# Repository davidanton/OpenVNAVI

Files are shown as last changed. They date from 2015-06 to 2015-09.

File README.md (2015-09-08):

# OpenVNAVI

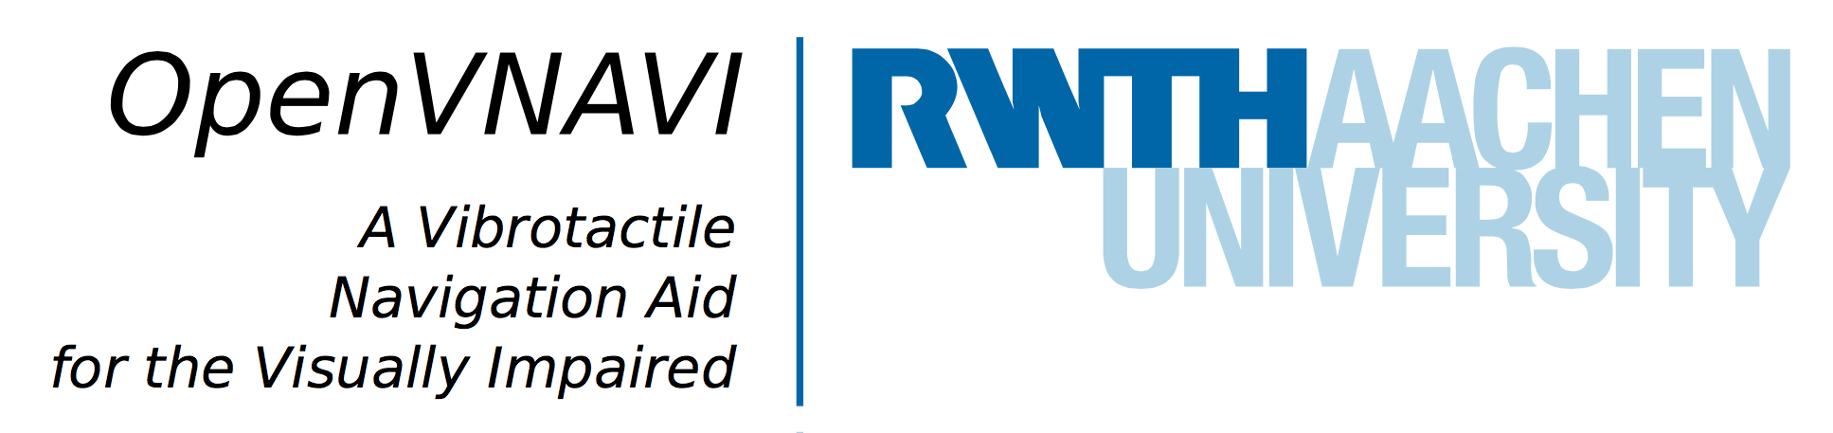
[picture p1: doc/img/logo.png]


**Bachelor Thesis at the Media Computing Group, Computer Science Department @ RWTH Aachen University (Germany)**
**Author:** [David Antón Sánchez](https://hci.rwth-aachen.de/sanchez)
**Project Website:** https://hci.rwth-aachen.de/openvnavi

---
#Wiki

- [Home](https://github.com/davidanton/OpenVNAVI/wiki)

- [Setting Up the Raspberry Pi 2](https://github.com/davidanton/OpenVNAVI/wiki/Setting-Up-the-Raspberry-Pi-2)

---

###System Description

OpenVNAVI is a vest equipped with a depth sensor and array of vibration motor units that allow people with visual impairment to avoid obstacles in the environment.

The ASUS Xtion PRO LIVE depth sensor, positioned onto the user’s chest scans the environment as the user moves. From the video feed of the depth sensor a frame is captured and then processed by the Raspberry Pi 2. Each frame is downsampled from 640x480 to 16x8 and each pixel is then mapped to a vibration motor unit forming an array positioned onto the user’s belly.

The grayscale value of each pixel on the lower resolution frame is assigned to a PWM voltage value generated by the Raspberry Pi 2 via PWM drivers that will drive each vibration motor obtaining a vibration amplitude value as a function of the proximity of an object.

With this method the vibration motor unit array is able to represent a vibratory image onto the user’s belly to help create a mental representation of the obstacles in the scene.

---

###Pictures

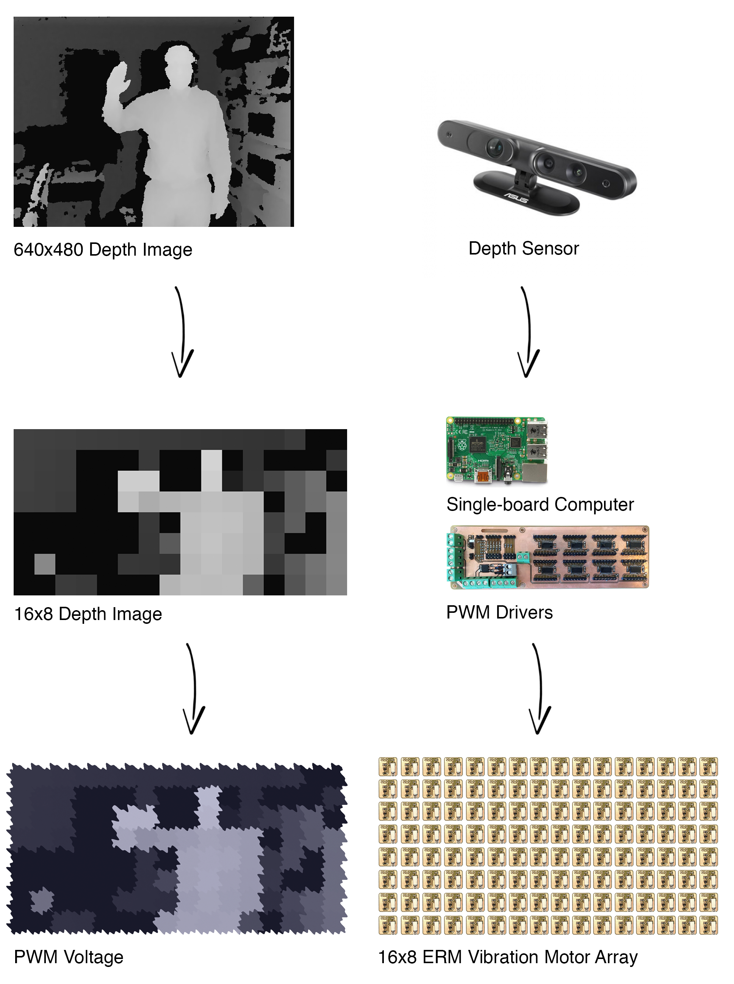
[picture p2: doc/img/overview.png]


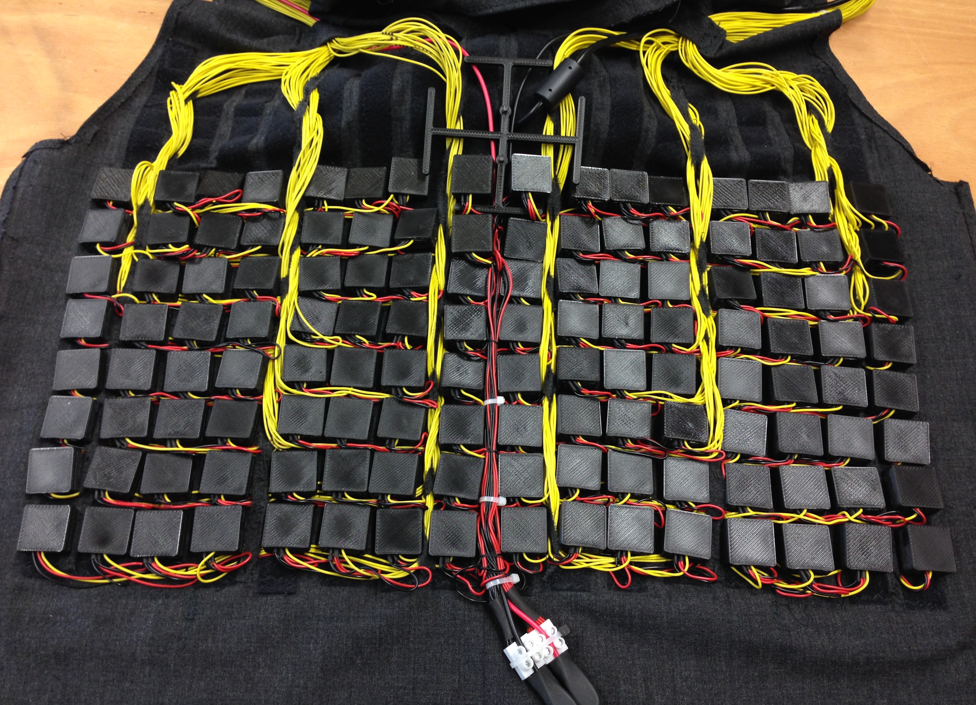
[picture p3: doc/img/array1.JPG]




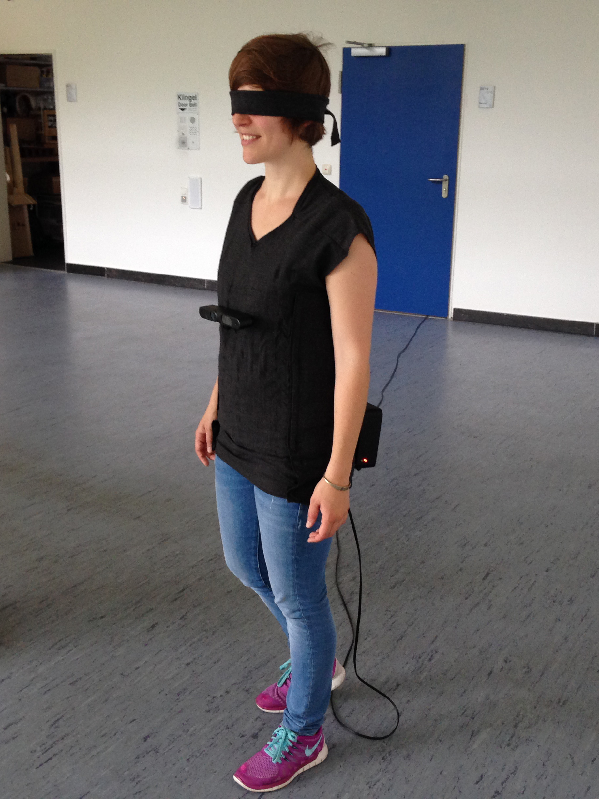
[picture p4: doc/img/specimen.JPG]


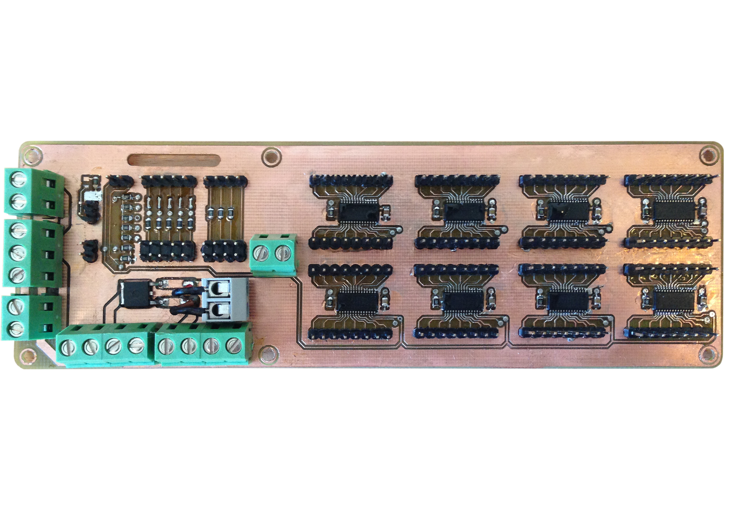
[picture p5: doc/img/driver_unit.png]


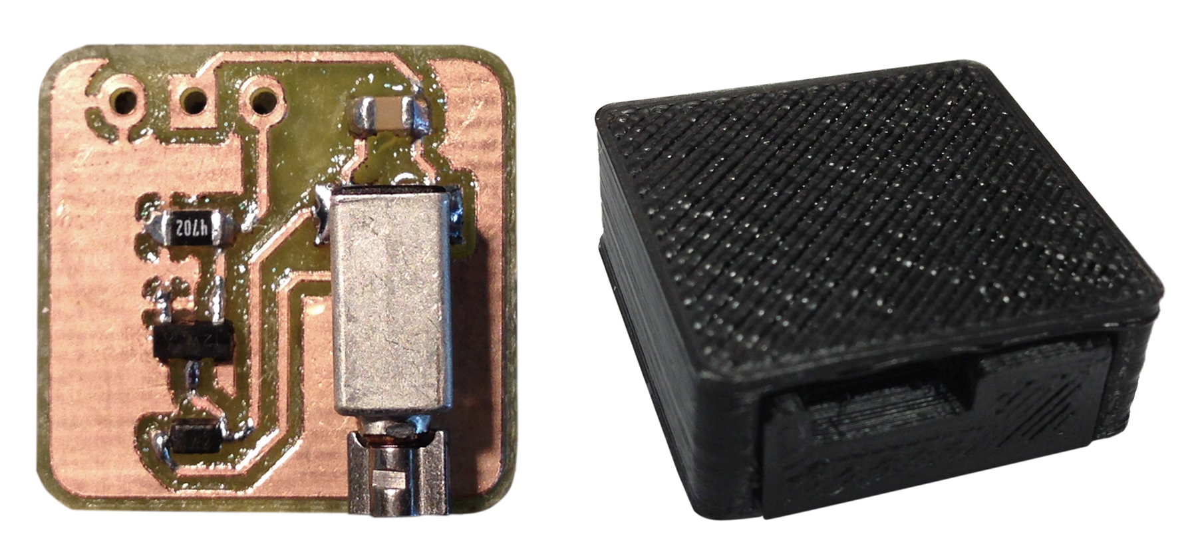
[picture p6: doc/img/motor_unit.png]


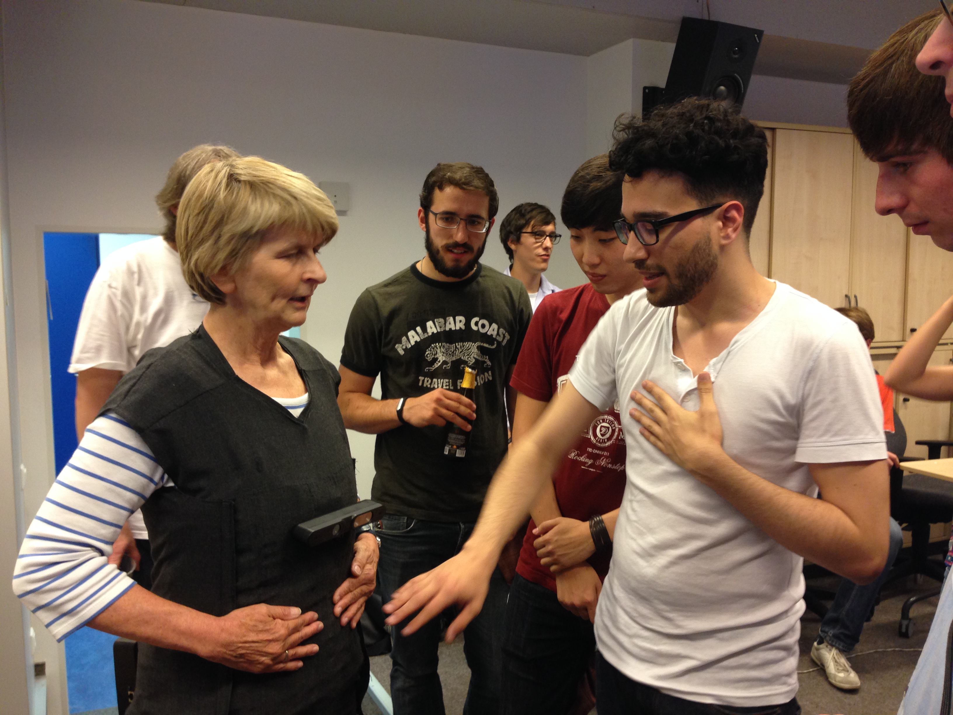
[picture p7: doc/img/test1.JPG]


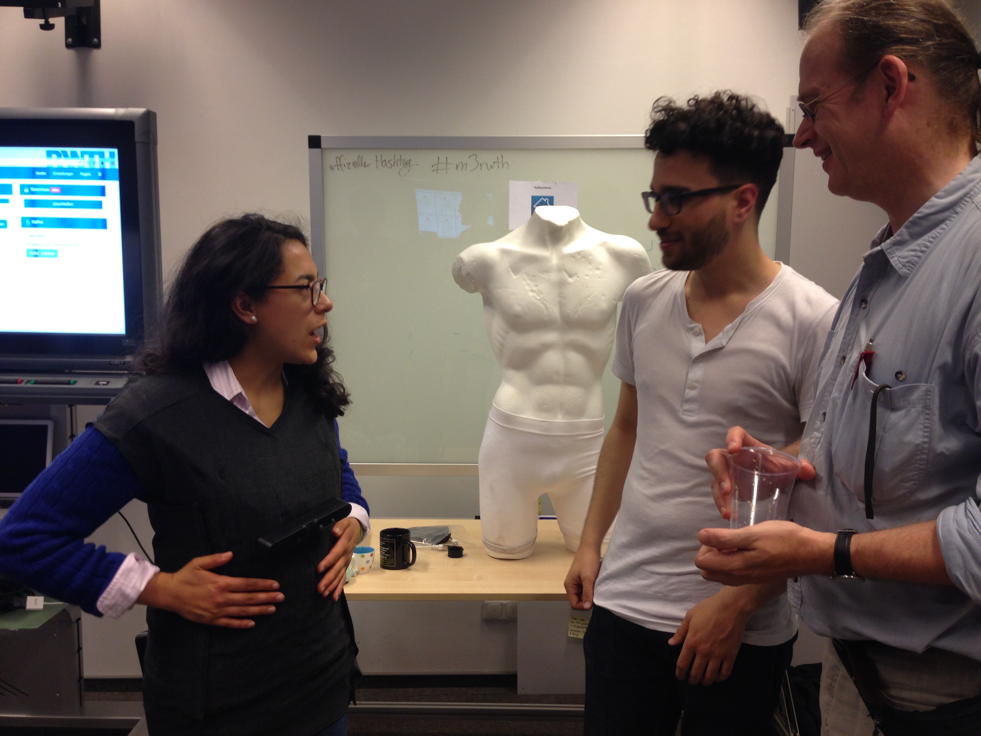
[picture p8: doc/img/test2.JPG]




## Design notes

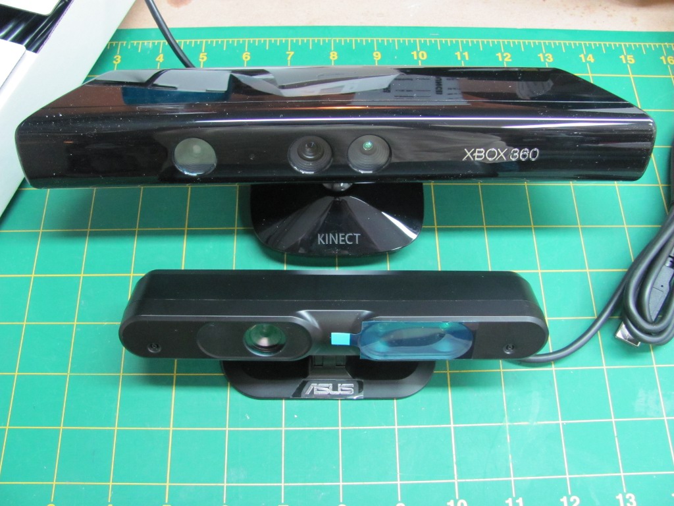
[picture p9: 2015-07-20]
hardware/sensor/xtion_vs_kinect.jpg

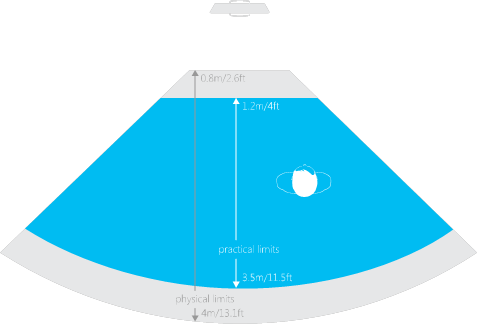
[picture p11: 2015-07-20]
hardware/sensor/top_range.png

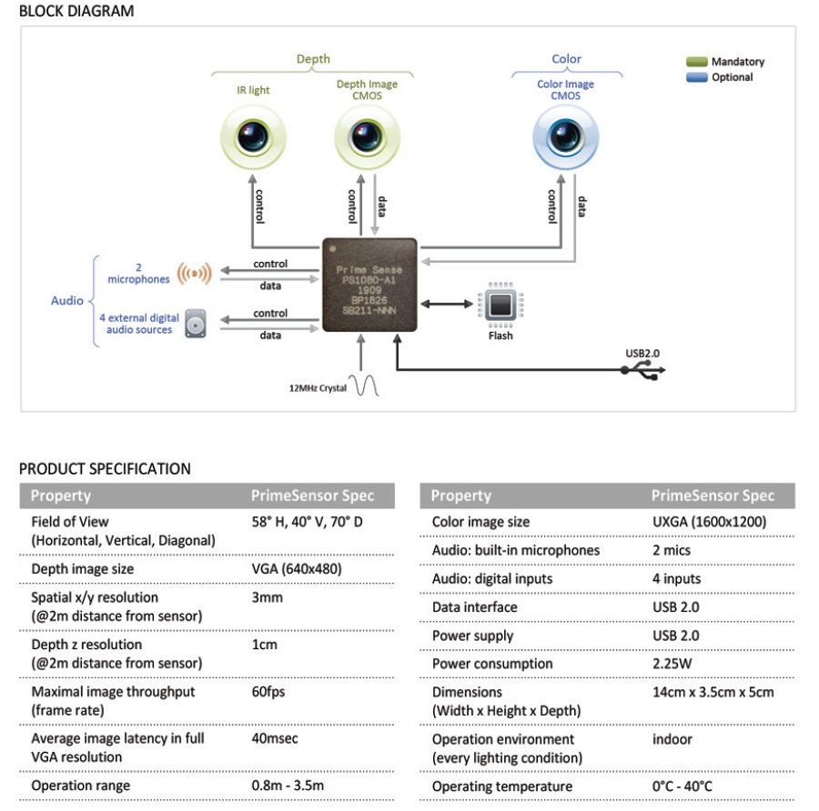
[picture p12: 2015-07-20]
hardware/sensor/xtion_specs.jpg

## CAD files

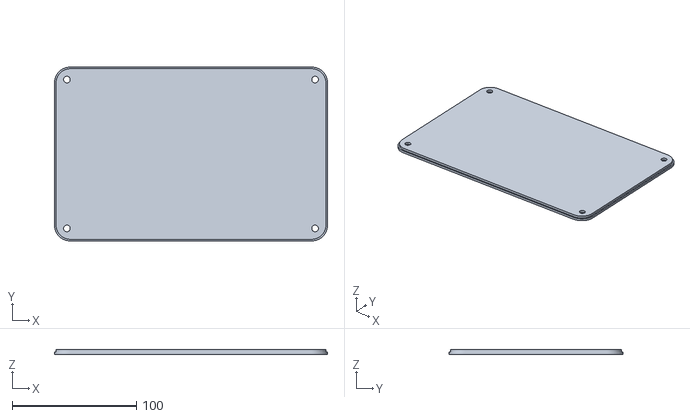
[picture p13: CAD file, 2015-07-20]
hardware/3D/enclosure/enclosure cover.stl
220.0 x 140.0 x 4.00

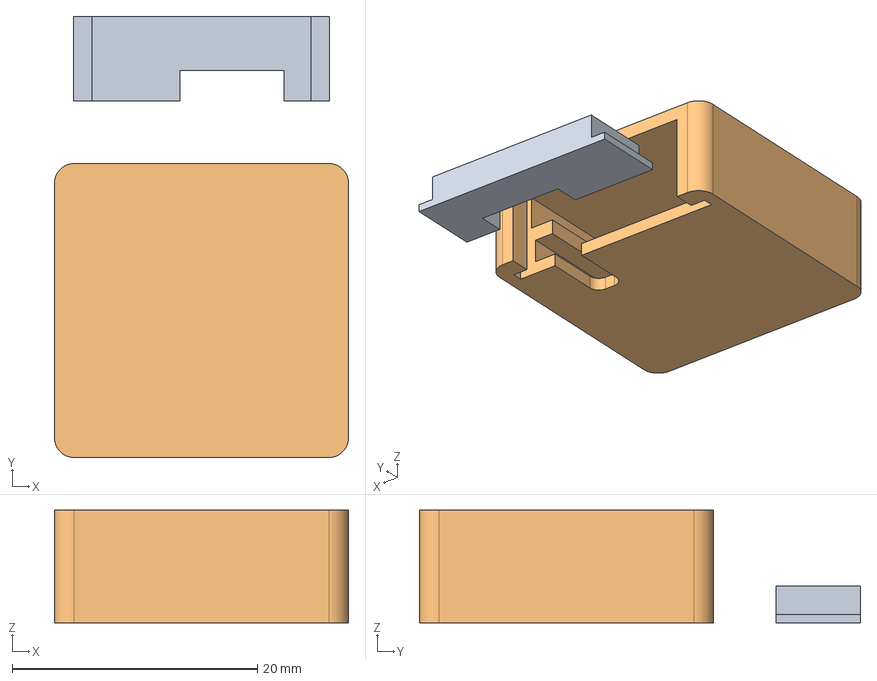
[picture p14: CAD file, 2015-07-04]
hardware/3D/motor unit/motor unit.FCStd
24.0 x 36.0 x 9.20 mm
Cover
Motor Unit

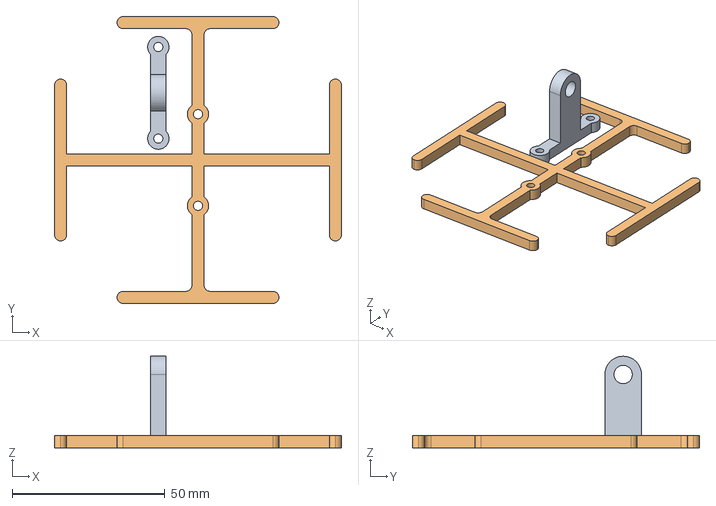
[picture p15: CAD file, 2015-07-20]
hardware/3D/sensor support/sensor support.FCStd
94.0 x 94.0 x 30.0 mm
sensor support a
sensor support b

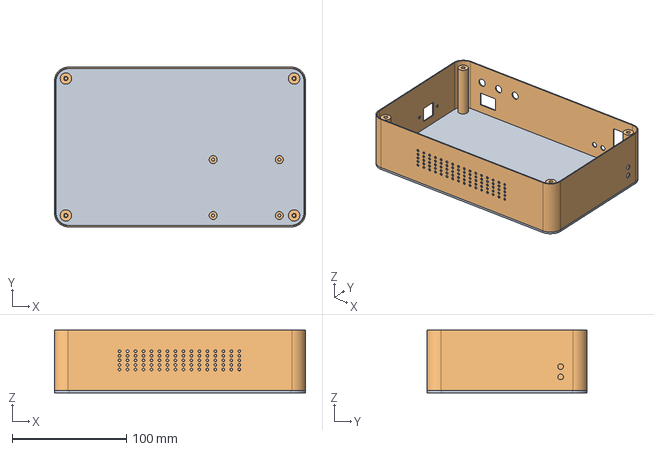
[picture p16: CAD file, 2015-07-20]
hardware/3D/enclosure/enclosure.FCStd
220.0 x 140.0 x 55.0 mm
cover
enclosure

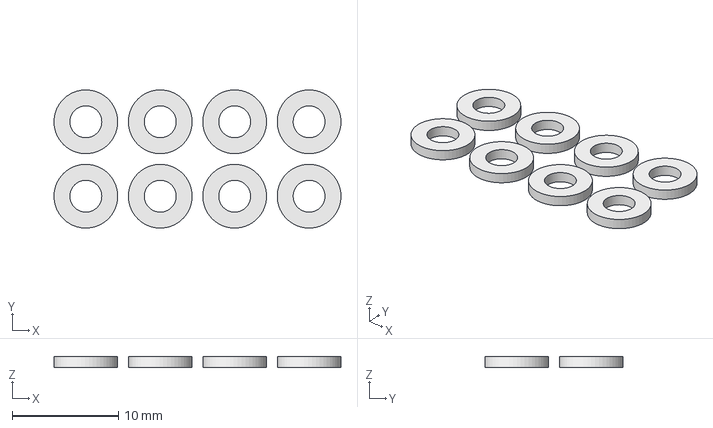
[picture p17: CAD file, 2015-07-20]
hardware/3D/washers/washers.FCStd
27.0 x 13.0 x 1.00 mm

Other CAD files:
hardware/3D/enclosure/enclosure.stl
hardware/3D/motor unit/motor unit.stl
hardware/3D/sensor support/sensor support.stl
hardware/3D/washers/washers.stl

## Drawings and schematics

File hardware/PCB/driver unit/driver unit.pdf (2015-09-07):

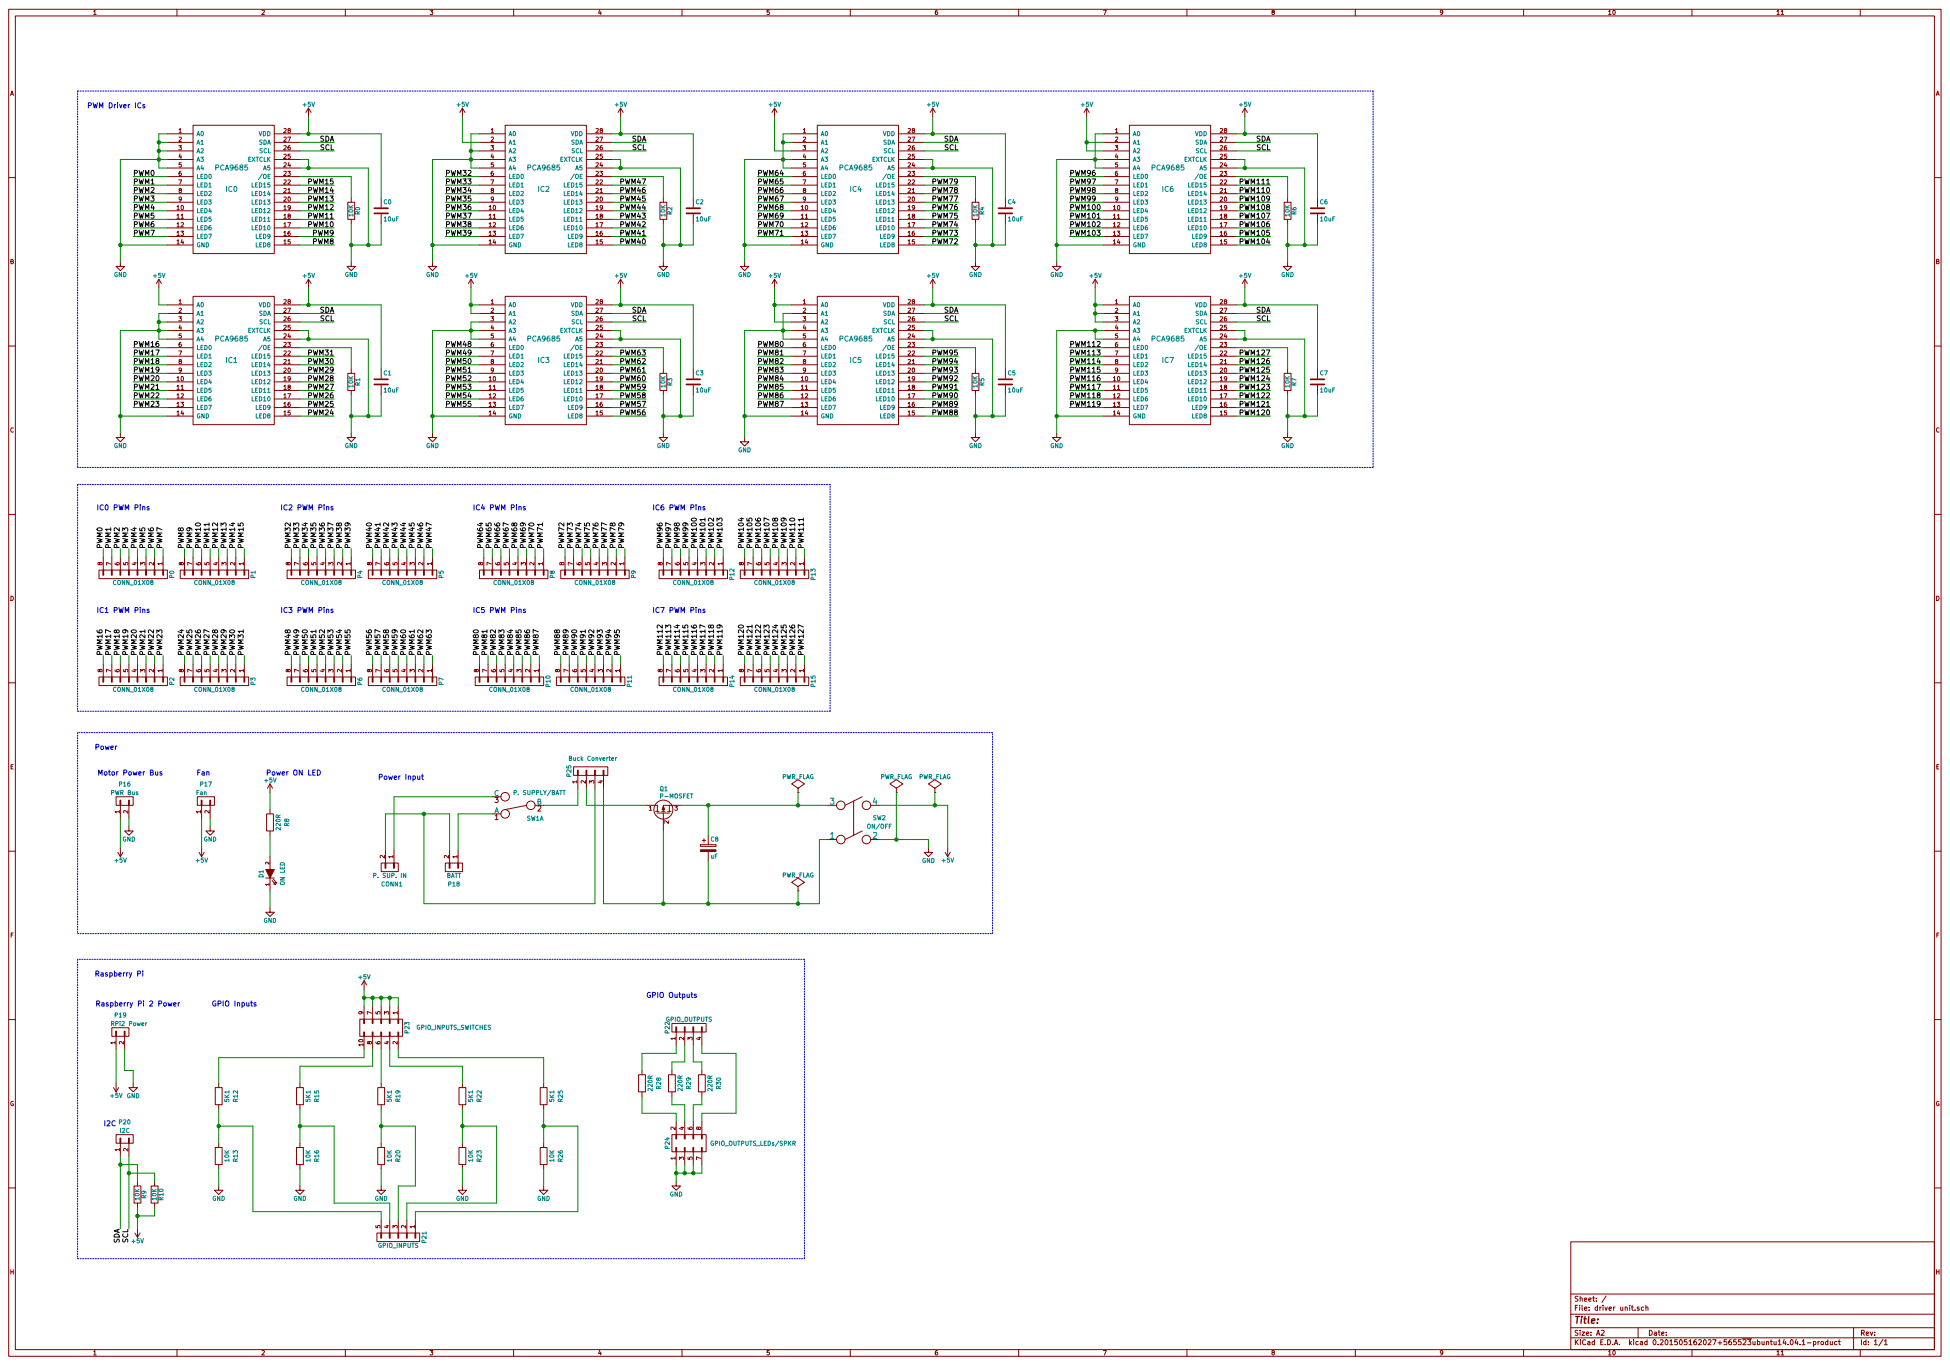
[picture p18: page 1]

IC7 PWM Pins Motor Power Bus

Id: 1/1 Title: File: driver unit.sch Sheet: /

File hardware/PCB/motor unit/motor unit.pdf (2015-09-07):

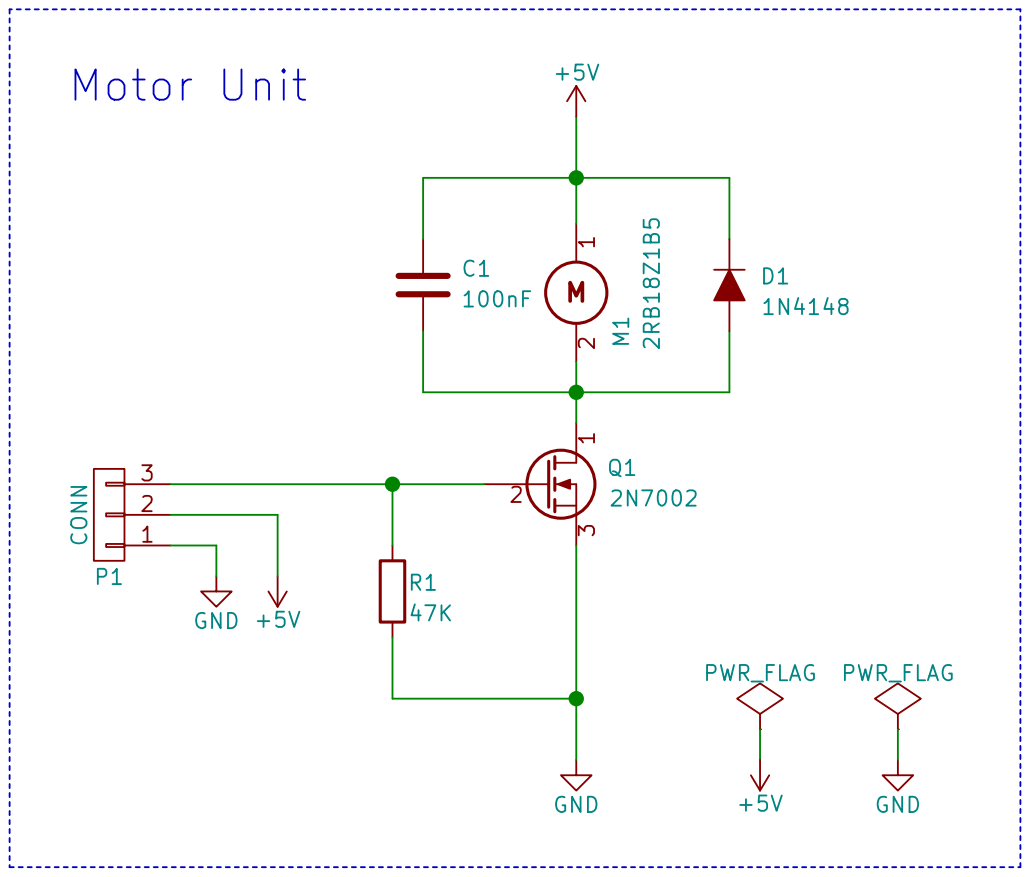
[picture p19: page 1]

Id: 1/1 Title: File: motor unit.sch Sheet: /

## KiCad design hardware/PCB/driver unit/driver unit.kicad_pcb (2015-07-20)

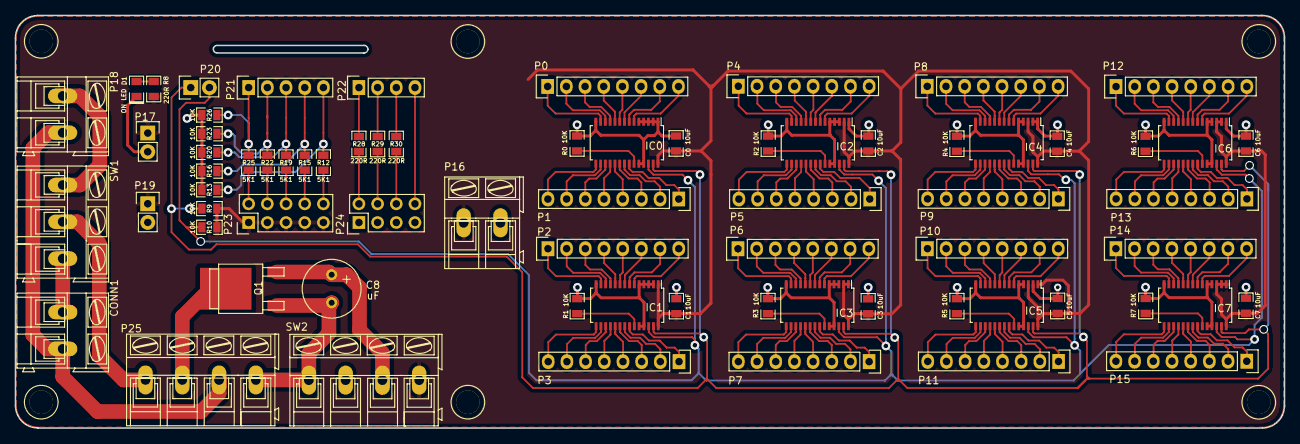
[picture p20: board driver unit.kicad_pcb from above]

Board: 2 copper layers, 172.5 x 56.1 mm, 72 parts (0 on the bottom side), 165 nets.

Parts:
C0, C1, C2, C3, C4, C5, C6, C7: 10uF; SMD0805
C8: uF; Elko_vert_11.5x8mm_RM3.5_CopperClear
CONN1: P. SUP. IN; AK300-2
D1: ON LED; SMD0805_LED
IC0, IC1, IC2, IC3, IC4, IC5, IC6, IC7: PCA9685; TSSOP-28_4.4x9.7mm_Pitch0.65mm
P0, P1, P2, P3, P4, P5, P6, P7, P8, P9, P10, P11, P12, P13, P14, P15: CONN_01X08; Pin_Header_Straight_1x08
P16: PWR Bus; AK300-2
P17: Fan; Pin_Header_Straight_1x02
P18: BATT; AK300-2
P19: RPi2 Power; Pin_Header_Straight_1x02
P20: I2C; Pin_Header_Straight_1x02
P21: GPIO_INPUTS; Pin_Header_Straight_1x05
P22: GPIO_OUTPUTS; Pin_Header_Straight_1x04
P23: GPIO_INPUTS_SWITCHES; Pin_Header_Straight_2x05
P24: GPIO_OUTPUTS_LEDs/SPKR; Pin_Header_Straight_2x04
P25: Buck Converter; AK300-4
Q1: P-MOSFET; TO-252
R0, R1, R2, R3, R4, R5, R6, R7, R9, R10, R13, R16, R20, R23, R26: 10K; SMD0805
R8, R28, R29, R30: 220R; SMD0805
R12, R15, R19, R22, R25: 5K1; SMD0805
SW1: P. SUPPLY/BATT; AK300-3
SW2: ON/OFF; AK300-4

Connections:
+5V: C0.1, C1.1, C2.1, C3.1, C4.1, C5.1, C6.1, C7.1, IC0.28, IC1.1, IC1.28, IC2.2, IC2.28, IC3.1, IC3.2, IC3.28, IC4.3, IC4.28, IC5.1, IC5.3, IC5.28, IC6.2, IC6.3, IC6.28, IC7.1, IC7.2, IC7.3, IC7.28, P16.1, P17.1, P19.1, P23.1, P23.3, P23.5, P23.7, P23.9, R8.1, R9.2, R10.2, SW2.4
/PWM0: IC0.6, P0.8
/PWM1: IC0.7, P0.7
/PWM2: IC0.8, P0.6
/PWM3: IC0.9, P0.5
/PWM4: IC0.10, P0.4
/PWM5: IC0.11, P0.3
/PWM6: IC0.12, P0.2
/PWM7: IC0.13, P0.1
/PWM8: IC0.15, P1.8
/PWM9: IC0.16, P1.7
/PWM10: IC0.17, P1.6
/PWM11: IC0.18, P1.5
/PWM12: IC0.19, P1.4
/PWM13: IC0.20, P1.3
/PWM14: IC0.21, P1.2
/PWM15: IC0.22, P1.1
/PWM16: IC1.6, P2.8
/PWM17: IC1.7, P2.7
/PWM18: IC1.8, P2.6
/PWM19: IC1.9, P2.5
/PWM20: IC1.10, P2.4
/PWM21: IC1.11, P2.3
/PWM22: IC1.12, P2.2
/PWM23: IC1.13, P2.1
/PWM24: IC1.15, P3.8
/PWM25: IC1.16, P3.7
/PWM26: IC1.17, P3.6
/PWM27: IC1.18, P3.5
/PWM28: IC1.19, P3.4
/PWM29: IC1.20, P3.3
/PWM30: IC1.21, P3.2
/PWM31: IC1.22, P3.1
/PWM32: IC2.6, P4.8
/PWM33: IC2.7, P4.7
/PWM34: IC2.8, P4.6
/PWM35: IC2.9, P4.5
/PWM36: IC2.10, P4.4
/PWM37: IC2.11, P4.3
/PWM38: IC2.12, P4.2
/PWM39: IC2.13, P4.1
/PWM40: IC2.15, P5.8
/PWM41: IC2.16, P5.7
/PWM42: IC2.17, P5.6
/PWM43: IC2.18, P5.5
/PWM44: IC2.19, P5.4
/PWM45: IC2.20, P5.3
/PWM46: IC2.21, P5.2
/PWM47: IC2.22, P5.1
/PWM48: IC3.6, P6.8
/PWM49: IC3.7, P6.7
/PWM50: IC3.8, P6.6
/PWM51: IC3.9, P6.5
/PWM52: IC3.10, P6.4
/PWM53: IC3.11, P6.3
/PWM54: IC3.12, P6.2
/PWM55: IC3.13, P6.1
/PWM56: IC3.15, P7.8
/PWM57: IC3.16, P7.7
/PWM58: IC3.17, P7.6
/PWM59: IC3.18, P7.5
/PWM60: IC3.19, P7.4
/PWM61: IC3.20, P7.3
/PWM62: IC3.21, P7.2
/PWM63: IC3.22, P7.1
/PWM64: IC4.6, P8.8
/PWM65: IC4.7, P8.7
/PWM66: IC4.8, P8.6
/PWM67: IC4.9, P8.5
/PWM68: IC4.10, P8.4
/PWM69: IC4.11, P8.3
/PWM70: IC4.12, P8.2
/PWM71: IC4.13, P8.1
/PWM72: IC4.15, P9.8
/PWM73: IC4.16, P9.7
/PWM74: IC4.17, P9.6
/PWM75: IC4.18, P9.5
/PWM76: IC4.19, P9.4
/PWM77: IC4.20, P9.3
/PWM78: IC4.21, P9.2
/PWM79: IC4.22, P9.1
/PWM80: IC5.6, P10.8
/PWM81: IC5.7, P10.7
/PWM82: IC5.8, P10.6
/PWM83: IC5.9, P10.5
/PWM84: IC5.10, P10.4
/PWM85: IC5.11, P10.3
/PWM86: IC5.12, P10.2
/PWM87: IC5.13, P10.1
/PWM88: IC5.15, P11.8
/PWM89: IC5.16, P11.7
/PWM90: IC5.17, P11.6
/PWM91: IC5.18, P11.5
/PWM92: IC5.19, P11.4
/PWM93: IC5.20, P11.3
/PWM94: IC5.21, P11.2
/PWM95: IC5.22, P11.1
/PWM96: IC6.6, P12.8
/PWM97: IC6.7, P12.7
/PWM98: IC6.8, P12.6
/PWM99: IC6.9, P12.5
/PWM100: IC6.10, P12.4
/PWM101: IC6.11, P12.3
/PWM102: IC6.12, P12.2
/PWM103: IC6.13, P12.1
/PWM104: IC6.15, P13.8
/PWM105: IC6.16, P13.7
/PWM106: IC6.17, P13.6
/PWM107: IC6.18, P13.5
/PWM108: IC6.19, P13.4
/PWM109: IC6.20, P13.3
/PWM110: IC6.21, P13.2
/PWM111: IC6.22, P13.1
/PWM112: IC7.6, P14.8
/PWM113: IC7.7, P14.7
/PWM114: IC7.8, P14.6
/PWM115: IC7.9, P14.5
/PWM116: IC7.10, P14.4
/PWM117: IC7.11, P14.3
/PWM118: IC7.12, P14.2
/PWM119: IC7.13, P14.1
/PWM120: IC7.15, P15.8
/PWM121: IC7.16, P15.7
/PWM122: IC7.17, P15.6
/PWM123: IC7.18, P15.5
/PWM124: IC7.19, P15.4
/PWM125: IC7.20, P15.3
/PWM126: IC7.21, P15.2
/PWM127: IC7.22, P15.1
/SCL: IC0.26, IC1.26, IC2.26, IC3.26, IC4.26, IC5.26, IC6.26, IC7.26, P20.2, R10.1
/SDA: IC0.27, IC1.27, IC2.27, IC3.27, IC4.27, IC5.27, IC6.27, IC7.27, P20.1, R9.1
GND: C0.2, C1.2, C2.2, C3.2, C4.2, C5.2, C6.2, C7.2, D1.1, IC0.1, IC0.2, IC0.3, IC0.4, IC0.5, IC0.14, IC0.24, IC0.25, IC1.2, IC1.3, IC1.4, IC1.5, IC1.14, IC1.24, IC1.25, IC2.1, IC2.3, IC2.4, IC2.5, IC2.14, IC2.24, IC2.25, IC3.3, IC3.4, IC3.5, IC3.14, IC3.24, IC3.25, IC4.1, IC4.2, IC4.4, IC4.5, IC4.14, IC4.24, IC4.25, IC5.2, IC5.4, IC5.5, IC5.14, IC5.24, IC5.25, IC6.1, IC6.4, IC6.5, IC6.14, IC6.24, IC6.25, IC7.4, IC7.5, IC7.14, IC7.24, IC7.25, P16.2, P17.2, P19.2, P24.1, P24.3, P24.5, P24.7, R0.2, R1.2, R2.2, R3.2, R4.2, R5.2, R6.2, R7.2, R13.2, R16.2, R20.2, R23.2, R26.2, SW2.2
unnamed: C8.1, Q1.3, SW2.3
unnamed: C8.2, P25.4, Q1.2, SW2.1
unnamed: CONN1.1, SW1.3
unnamed: CONN1.2, P18.2, P25.3
unnamed: D1.2, R8.2
unnamed: IC0.23, R0.1
unnamed: IC1.23, R1.1
unnamed: IC2.23, R2.1
unnamed: IC3.23, R3.1
unnamed: IC4.23, R4.1
unnamed: IC5.23, R5.1
unnamed: IC6.23, R6.1
unnamed: IC7.23, R7.1
unnamed: P18.1, SW1.1
unnamed: P21.1, R25.2, R26.1
unnamed: P21.2, R22.2, R23.1
unnamed: P21.3, R19.2, R20.1
unnamed: P21.4, R15.2, R16.1
unnamed: P21.5, R12.2, R13.1
unnamed: P22.1, R28.1
unnamed: P22.2, R29.1
unnamed: P22.3, R30.1
unnamed: P22.4, P24.8
unnamed: P23.2, R25.1
unnamed: P23.4, R22.1
unnamed: P23.6, R19.1
unnamed: P23.8, R15.1
unnamed: P23.10, R12.1
unnamed: P24.2, R28.2
unnamed: P24.4, R29.2
unnamed: P24.6, R30.2
unnamed: P25.1, SW1.2
unnamed: P25.2, Q1.1

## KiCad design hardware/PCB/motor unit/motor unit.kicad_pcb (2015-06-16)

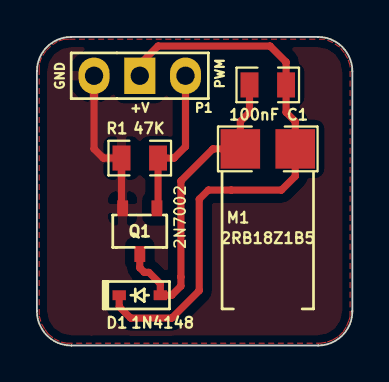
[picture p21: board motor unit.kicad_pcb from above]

Board: 2 copper layers, 17.5 x 17.1 mm, 6 parts (0 on the bottom side), 4 nets.

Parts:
C1: 100nF; SMD0805
D1: 1N4148; SOD-323
M1: 2RB18Z1B5; Vibration_motor
P1: CONN; Pin_Header_Straight_1x03_MOD
Q1: 2N7002; SOT23-5_MOD_PINOUT
R1: 47K; SMD0805

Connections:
+5V: C1.1, D1.1, M1.1, P1.2
GND: P1.1, Q1.3, R1.2
unnamed: C1.2, D1.2, M1.2, Q1.1
unnamed: P1.3, Q1.2, R1.1

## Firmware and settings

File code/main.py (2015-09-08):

#!/usr/bin/python
# -*- coding: utf-8 -*-

"""
//////////////////////////////////////////////////////////////////////////////
==============================================================================
OpenVNAVI (Open Vibrotactile Navigation Aid for the Visually Impaired)
Author: David Antón Sánchez
License: GPLv3
github.com/davidanton/OpenVNAVI
==============================================================================
//////////////////////////////////////////////////////////////////////////////
"""

__author__ = "David Anton Sanchez"
__license__ = "GPLv3"


# ============================================================================
# Imports
# ============================================================================
import cv2
import numpy as np
import sys
import os
import time
import RPi.GPIO as GPIO
from PWM_driver import PWM
from flask import Flask, jsonify, render_template, request
import multiprocessing as mp
import timeit


# ============================================================================
# Constants
# ============================================================================
""" Each device and channel is identified by an integer. The C++
version of OpenCV defines some constants for the identifiers of
certain devices and channels. However, these constants are not
defined in the Python version and the assignment needs to be
performed manually. """

# Devices.
CV_CAP_OPENNI = 900 # OpenNI (for Microsoft Kinect)
CV_CAP_OPENNI_ASUS = 910 # OpenNI (for Asus Xtion)
# Channels of an OpenNI-compatible depth generator.
CV_CAP_OPENNI_DEPTH_MAP = 0 # Depth values in mm (CV_16UC1)
CV_CAP_OPENNI_POINT_CLOUD_MAP = 1 # XYZ in meters (CV_32FC3)
CV_CAP_OPENNI_DISPARITY_MAP = 2 # Disparity in pixels (CV_8UC1)
CV_CAP_OPENNI_DISPARITY_MAP_32F = 3 # Disparity in pixels (CV_32FC1)
CV_CAP_OPENNI_VALID_DEPTH_MASK = 4 # CV_8UC1
# Channels of an OpenNI-compatible RGB image generator.
CV_CAP_OPENNI_BGR_IMAGE = 5
CV_CAP_OPENNI_GRAY_IMAGE = 6

# ============================================================================
# Global variable
# ============================================================================
isMotorOn = False # Flag for start/stop button.


# ============================================================================
# Definitions
# ============================================================================
def depthTest():

    """ Grabs frames from different channels, multiplies the output
    by different constant gain values and saves the PNG frames
    for visual inspection of the range of depth values of a scene.
    The folder named "test_frames" must be created. """

    abc = (["a","b","c","d","e","f","g","h","i","j","k","l","m",
          "n","o","p","q","r","s","t","u","v","w","x","y","z"])
    values = 7
    testGain = 5
    maxChannel = 4
    for i in range(0, values):
        for j in range(0, maxChannel):
            capture.grab()
            print "Retrieving channel " + str(j) + abc[i]
            success, rawFrame = capture.retrieve(channel = j)
            frame640j = testGain * i * rawFrame
            cv2.imwrite("test_frames/" + str(j) + abc[i] + ".png", frame640j)

def sweepTest():

    """ Sweeps up and down for all motors. """

    minPWM = 300
    maxPWM = 3000
    step = 100
    for i in range(minPWM,maxPWM,step):
        for row in range(0,8):
            for col in range(0,16):
                IC[row].setPWM(col, 0, i)
                time.sleep(0.001)
                print ("IC: " + str(row) + " motor: " +
                      str(col) + " PWM: " + str(i))

    for i in range(maxPWM,minPWM,-step):
        for row in range(0,8):
            for col in range(0,16):
                IC[row].setPWM(col, 0, i)
                time.sleep(0.001)
                print ("IC: " + str(row) + " motor: " +
                      str(col) + " PWM: " + str(i))

def strobeTest(row):

    """ Strobes maximum and minimum values for a given row. """

    minPWM = 300
    maxPWM = 3000
    IC[row].setAllPWM(0, minPWM)
    time.sleep (1)
    IC[row].setAllPWM(0, maxPWM)
    time.sleep (1)

def fadeIn():

    """ Ramps from low to medium vibration values for a smooth
    transition. """

    minPWM = 300
    maxPWM = 1000
    step = 10
    for i in range(minPWM,maxPWM,step):
        for row in range(0,8):
            IC[row].setAllPWM(0, i)

def fadeOut():

    """ Ramps from medium to low vibration values for a smooth
    transition. """

    minPWM = 300
    maxPWM = 1000
    step = 10
    for i in range(maxPWM, minPWM, -step):
        for row in range(0,8):
            IC[row].setAllPWM(0, i)

def beep(number, t):

    """ Simple buzzer beep. Takes number of beeps and the duration. """

    GPIO.setwarnings(False)
    GPIO.setup(12, GPIO.OUT)
    for i in range (0, number):
        buzzer = GPIO.PWM(12, 5000)
        time.sleep(t)
        buzzer.start(92)
        time.sleep(t)
        buzzer.stop()

def pause():

    """ Pause function. """
    global isMotorOn

    fadeOut()
    for row in range(0, 8):
        IC[row].setAllPWM(0, 0)
    print "System paused by the user."
    time.sleep(0.5)
    beep(1, 0.2)
    print "System ready, press switch to continue..."
    GPIO.wait_for_edge(18, GPIO.RISING)
    fadeIn()
    isMotorOn = True

def getFrame():

    """ Gets the frame from the sensor and stores it it.
    Returns 16x8 numpy array. """

    capture.grab()
    success, rawFrame = capture.retrieve(channel = channel)
    frame640 = gain * rawFrame
    frame16 = cv2.resize(frame640, (16, 8))
    frame16 = frame16.astype(int)
    # For debugging
    # cv2.imwrite("frame640.png", frame640)
    # cv2.imwrite("frame16.png", frame16)
    # print frame16
    return frame16

def setVibration(frame = None):

    """ Sets PWM values to each vibration motor unit. """

    if frame is None:
        frame = getFrame()
    mappingFunction = 8 # Mapping of grayscale values to PWM values.
    PWM16 = mappingFunction * frame
    maxPWM = 3060
    for row in range(0,8):
        for col in range (0,16):
            if PWM16[row,col] > maxPWM:
                PWM16[row,col] = maxPWM
            elif PWM16[row,col] == 0:
                # PWM16[row,col] = maxPWM
            else:
                IC[row].setPWM(col,0,(PWM16[row,col]))
                # print (PWM16[row,col]),
        # print "\n"


# ============================================================================
# Vibration renderer process
# ============================================================================

def rendererProcess(webQueue, ipcQueue):

    """ Entry point for the renderer process. """
    global isMotorOn

    # Initialization of PWM drivers. PWM(0x40, debug=True) for debugging.
    global IC
    IC = []
    freq = 490
    for i in range(0,8):
        IC.append(PWM(0x40+i))
        IC[i].setPWMFreq(freq)

    # Initialization of the sensor.
    global sensor
    sensor = CV_CAP_OPENNI_ASUS
    global channel
    channel = 3
    global gain
    gain = 5
    global capture
    capture = cv2.VideoCapture(sensor)
    capture.open(sensor)
    while not capture.isOpened():
        print "Couldn't open sensor. Is it connected?"
        time.sleep(100)
    print "Sensor opened successfully"

    # camera benchmarking
    # getFrame()
    # repCount = 50
    # print "Benchmarking camera for %d frames" % repCount
    # callTime = timeit.timeit("getFrame()", setup="from __main__ import getFrame", number = repCount)
    # print "getFrame() FPS: %.3f" % (repCount / callTime)

    # GPIO initialization.
    GPIO.setmode(GPIO.BCM)
    GPIO.setup(18, GPIO.IN, pull_up_down=GPIO.PUD_DOWN)
    sw1 = GPIO.input(18) # Input NO switch.

    # Waits for sw1 to be pressed.
    print "System ready, press switch to continue..."
    beep(1, 0.2)
    GPIO.wait_for_edge(18, GPIO.RISING)
    fadeIn()
    isMotorOn = True

    shouldTerminate = False

    global sourceMode
    sourceMode = "kinect"

    while not shouldTerminate:
        gpioValue = GPIO.input(18)
        if ((gpioValue == True) and (isMotorOn == True)):
            pause()

        # depthTest()
        # sweepTest()
        # strobeTest(0)
        # getFrame()
        if not webQueue.empty():
            requestJson = webQueue.get()
            nextMode = requestJson["mode"]
            if nextMode is not sourceMode:
                print "Switching to mode %s" % nextMode

        if sourceMode == "web":
            frame = np.array(requestJson["motors"])
            setVibration(frame)
        elif sourceMode == "kinect":
            setVibration()

        if not ipcQueue.empty():
            ipcCommand = ipcQueue.get()
            if ipcCommand == "terminate":
                shouldTerminate = True

    print "[Renderer] shutdown requested"
    GPIO.cleanup()
    for i in range(0, 8):
        IC[i].setAllPWM(0, 0)

    print "[Renderer] successfully shutdown"


# ============================================================================
# Web server process
# ============================================================================
webServer = Flask(__name__)
webServer.debug = True


@webServer.route("/")
def serve():
    """ Web root. """
    return render_template('index.html')


@webServer.route('/_send_motors', methods=["PUT", "POST"])
def send_motors():

    """ Handles AJAX requests. """

    requestJson = request.get_json()
    webServer.extensions['queue'].put(requestJson)

    retVal = {"message": "hi from Flask"}
    return jsonify(**retVal)


def webserverProcess(webQueue, ipcQueue):

    """ Entry point for the web server process. """
    if not hasattr(webServer, 'extensions'):
        webServer.extensions = {}
    webServer.extensions['queue'] = webQueue

    webServer.run(host='0.0.0.0', use_reloader=False)

    while True:
        ipcCommand = ipcQueue.get()
        if ipcCommand == "terminate":
            print "[WebServer] shutdown requested"
            return


# ============================================================================
# Main function
# ============================================================================
def main():

    # for inter-process communication
    webQueue = mp.Queue()
    ipcQueue = mp.Queue()

    # web server process
    p_webserver = mp.Process(target=webserverProcess, args=(webQueue, ipcQueue))
    p_webserver.start()

    # jacket renderer process
    p_renderer = mp.Process(target=rendererProcess, args=(webQueue, ipcQueue))
    p_renderer.start()

    workers = [p_webserver, p_renderer]
    try:
        for worker in workers:
            worker.join()
    except KeyboardInterrupt:
        print "[Main] received Ctrl + C"
        ipcQueue.put("terminate")
        for worker in workers:
            worker.join()


if __name__ == "__main__":
    main()

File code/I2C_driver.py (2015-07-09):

#!/usr/bin/python

""" Copyright (c) 2012-2013 Limor Fried, Kevin Townsend and Mikey Sklar for 
Adafruit Industries. All rights reserved. """

import re
import smbus

# ===========================================================================
# Adafruit_I2C Class
# ===========================================================================

class Adafruit_I2C(object):

  @staticmethod
  def getPiRevision():
    "Gets the version number of the Raspberry Pi board"
    # Revision list available at: http://elinux.org/RPi_HardwareHistory#Board_Revision_History
    try:
      with open('/proc/cpuinfo', 'r') as infile:
        for line in infile:
          # Match a line of the form "Revision : 0002" while ignoring extra
          # info in front of the revsion (like 1000 when the Pi was over-volted).
          match = re.match('Revision\s+:\s+.*(\w{4})$', line)
          if match and match.group(1) in ['0000', '0002', '0003']:
            # Return revision 1 if revision ends with 0000, 0002 or 0003.
            return 1
          elif match:
            # Assume revision 2 if revision ends with any other 4 chars.
            return 2
        # Couldn't find the revision, assume revision 0 like older code for compatibility.
        return 0
    except:
      return 0

  @staticmethod
  def getPiI2CBusNumber():
    # Gets the I2C bus number /dev/i2c#
    return 1 if Adafruit_I2C.getPiRevision() > 1 else 0

  def __init__(self, address, busnum=-1, debug=False):
    self.address = address
    # By default, the correct I2C bus is auto-detected using /proc/cpuinfo
    # Alternatively, you can hard-code the bus version below:
    # self.bus = smbus.SMBus(0); # Force I2C0 (early 256MB Pi's)
    # self.bus = smbus.SMBus(1); # Force I2C1 (512MB Pi's)
    self.bus = smbus.SMBus(busnum if busnum >= 0 else Adafruit_I2C.getPiI2CBusNumber())
    self.debug = debug

  def reverseByteOrder(self, data):
    "Reverses the byte order of an int (16-bit) or long (32-bit) value"
    # Courtesy Vishal Sapre
    byteCount = len(hex(data)[2:].replace('L','')[::2])
    val       = 0
    for i in range(byteCount):
      val    = (val << 8) | (data & 0xff)
      data >>= 8
    return val

  def errMsg(self):
    print "Error accessing 0x%02X: Check your I2C address" % self.address
    return -1

  def write8(self, reg, value):
    "Writes an 8-bit value to the specified register/address"
    try:
      self.bus.write_byte_data(self.address, reg, value)
      if self.debug:
        print "I2C: Wrote 0x%02X to register 0x%02X" % (value, reg)
    except IOError, err:
      return self.errMsg()

  def write16(self, reg, value):
    "Writes a 16-bit value to the specified register/address pair"
    try:
      self.bus.write_word_data(self.address, reg, value)
      if self.debug:
        print ("I2C: Wrote 0x%02X to register pair 0x%02X,0x%02X" %
         (value, reg, reg+1))
    except IOError, err:
      return self.errMsg()

  def writeRaw8(self, value):
    "Writes an 8-bit value on the bus"
    try:
      self.bus.write_byte(self.address, value)
      if self.debug:
        print "I2C: Wrote 0x%02X" % value
    except IOError, err:
      return self.errMsg()

  def writeList(self, reg, list):
    "Writes an array of bytes using I2C format"
    try:
      if self.debug:
        print "I2C: Writing list to register 0x%02X:" % reg
        print list
      self.bus.write_i2c_block_data(self.address, reg, list)
    except IOError, err:
      return self.errMsg()

  def readList(self, reg, length):
    "Read a list of bytes from the I2C device"
    try:
      results = self.bus.read_i2c_block_data(self.address, reg, length)
      if self.debug:
        print ("I2C: Device 0x%02X returned the following from reg 0x%02X" %
         (self.address, reg))
        print results
      return results
    except IOError, err:
      return self.errMsg()

  def readU8(self, reg):
    "Read an unsigned byte from the I2C device"
    try:
      result = self.bus.read_byte_data(self.address, reg)
      if self.debug:
        print ("I2C: Device 0x%02X returned 0x%02X from reg 0x%02X" %
         (self.address, result & 0xFF, reg))
      return result
    except IOError, err:
      return self.errMsg()

  def readS8(self, reg):
    "Reads a signed byte from the I2C device"
    try:
      result = self.bus.read_byte_data(self.address, reg)
      if result > 127: result -= 256
      if self.debug:
        print ("I2C: Device 0x%02X returned 0x%02X from reg 0x%02X" %
         (self.address, result & 0xFF, reg))
      return result
    except IOError, err:
      return self.errMsg()

  def readU16(self, reg, little_endian=True):
    "Reads an unsigned 16-bit value from the I2C device"
    try:
      result = self.bus.read_word_data(self.address,reg)
      # Swap bytes if using big endian because read_word_data assumes little 
      # endian on ARM (little endian) systems.
      if not little_endian:
        result = ((result << 8) & 0xFF00) + (result >> 8)
      if (self.debug):
        print "I2C: Device 0x%02X returned 0x%04X from reg 0x%02X" % (self.address, result & 0xFFFF, reg)
      return result
    except IOError, err:
      return self.errMsg()

  def readS16(self, reg, little_endian=True):
    "Reads a signed 16-bit value from the I2C device"
    try:
      result = self.readU16(reg,little_endian)
      if result > 32767: result -= 65536
      return result
    except IOError, err:
      return self.errMsg()

if __name__ == '__main__':
  try:
    bus = Adafruit_I2C(address=0)
    print "Default I2C bus is accessible"
  except:
    print "Error accessing default I2C bus"

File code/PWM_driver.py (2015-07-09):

#!/usr/bin/python

""" Copyright (c) 2012-2013 Limor Fried, Kevin Townsend and Mikey Sklar for 
Adafruit Industries. All rights reserved. """

import time
import math
from I2C_driver import Adafruit_I2C

# ============================================================================
# Adafruit PCA9685 16-Channel PWM Servo Driver
# ============================================================================

class PWM :
  # Registers/etc.
  __MODE1              = 0x00
  __MODE2              = 0x01
  __SUBADR1            = 0x02
  __SUBADR2            = 0x03
  __SUBADR3            = 0x04
  __PRESCALE           = 0xFE
  __LED0_ON_L          = 0x06
  __LED0_ON_H          = 0x07
  __LED0_OFF_L         = 0x08
  __LED0_OFF_H         = 0x09
  __ALL_LED_ON_L       = 0xFA
  __ALL_LED_ON_H       = 0xFB
  __ALL_LED_OFF_L      = 0xFC
  __ALL_LED_OFF_H      = 0xFD

  # Bits
  __RESTART            = 0x80
  __SLEEP              = 0x10
  __ALLCALL            = 0x01
  __INVRT              = 0x10
  __OUTDRV             = 0x04

  general_call_i2c = Adafruit_I2C(0x00)

  @classmethod
  def softwareReset(cls):
    "Sends a software reset (SWRST) command to all the servo drivers on the bus"
    cls.general_call_i2c.writeRaw8(0x06)        # SWRST

  def __init__(self, address=0x40, debug=False):
    self.i2c = Adafruit_I2C(address)
    self.i2c.debug = debug
    self.address = address
    self.debug = debug
    if (self.debug):
      print "Reseting PCA9685 MODE1 (without SLEEP) and MODE2"
    self.setAllPWM(0, 0)
    self.i2c.write8(self.__MODE2, self.__OUTDRV)
    self.i2c.write8(self.__MODE1, self.__ALLCALL)
    time.sleep(0.005)                                       # wait for oscillator
    
    mode1 = self.i2c.readU8(self.__MODE1)
    mode1 = mode1 & ~self.__SLEEP                 # wake up (reset sleep)
    self.i2c.write8(self.__MODE1, mode1)
    time.sleep(0.005)                             # wait for oscillator

  def setPWMFreq(self, freq):
    "Sets the PWM frequency"
    prescaleval = 25000000.0    # 25MHz
    prescaleval /= 4096.0       # 12-bit
    prescaleval /= float(freq)
    prescaleval -= 1.0
    if (self.debug):
      print "Setting PWM frequency to %d Hz" % freq
      print "Estimated pre-scale: %d" % prescaleval
    prescale = math.floor(prescaleval + 0.5)
    if (self.debug):
      print "Final pre-scale: %d" % prescale

    oldmode = self.i2c.readU8(self.__MODE1);
    newmode = (oldmode & 0x7F) | 0x10             # sleep
    self.i2c.write8(self.__MODE1, newmode)        # go to sleep
    self.i2c.write8(self.__PRESCALE, int(math.floor(prescale)))
    self.i2c.write8(self.__MODE1, oldmode)
    time.sleep(0.005)
    self.i2c.write8(self.__MODE1, oldmode | 0x80)

  def setPWM(self, channel, on, off):
    "Sets a single PWM channel"
    self.i2c.write8(self.__LED0_ON_L+4*channel, on & 0xFF)
    self.i2c.write8(self.__LED0_ON_H+4*channel, on >> 8)
    self.i2c.write8(self.__LED0_OFF_L+4*channel, off & 0xFF)
    self.i2c.write8(self.__LED0_OFF_H+4*channel, off >> 8)

  def setAllPWM(self, on, off):
    "Sets a all PWM channels"
    self.i2c.write8(self.__ALL_LED_ON_L, on & 0xFF)
    self.i2c.write8(self.__ALL_LED_ON_H, on >> 8)
    self.i2c.write8(self.__ALL_LED_OFF_L, off & 0xFF)
    self.i2c.write8(self.__ALL_LED_OFF_H, off >> 8)

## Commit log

2015-06-04 Added Motor Unit PCB and KiCAD libraries
    [motor unit PCB.kicad_pcb, motor unit PCB.sch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]
2015-06-04 Add Motor Unit FreeCAD 3D files
    [motor unit 3D.FCStd, motor unit 3D.stl]
2015-06-04 Fix KiCAD libraries folder
2015-06-05 Add final motor unit PCB gerbers
    [motor unit PCB-Edge_Cuts.gbr, motor unit PCB-F_Cu.gbr, motor unit PCB-F_SilkS.gbr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]
2015-06-10 Update motor unit 3D files
    [motor unit 3D.FCStd, motor unit 3D.stl]
2015-06-10 Update motor unit PCB files
    [motor unit PCB.kicad_pcb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]
2015-06-10 Update motor unit 3D
    [motor unit 3D.FCStd, motor unit 3D.stl]
2015-06-10 Update motor unit 3D and PCB
    [motor unit 3D.FCStd, motor unit 3D.stl, motor unit PCB.kicad_pcb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]
2015-06-13 Update motor unit PCB
    [motor unit PCB.kicad_pcb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]
2015-06-16 Fix motor unit PCB
    [motor unit PCB.kicad_pcb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]
2015-07-04 Fix Motor Unit 3D cable opening size
    [motor unit 3D.FCStd, motor unit 3D.stl]
2015-07-09 Add Raspberry Pi 2 python code
2015-07-10 Add strobe vibration function, code cleanup
    [main.py]
2015-07-14 Fix silkscreen placement
    [motor unit PCB.sch]
2015-07-20 Add sensor specs files
2015-07-20 Add driver PCB
    [driver PCB.kicad_pcb, driver PCB.sch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]
2015-07-20 Add 3D enclosure, sensor support and washers
    [driver unit.kicad_pcb, driver unit.sch, enclosure cover.stl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]
2015-08-15 Fix PWM not set when sensor data = 0, update driver unit and motor unit
    [main.py]
2015-08-15 Web server for setting vibration motor levels
    [main.py]
2015-08-16 Fix black border removed from frame640, providing better downsampling results
    [main.py]
2015-08-16 Add distance detection threshold to reduce the vibration noise of distant objects, minor cleanup
    [main.py]
2015-08-17 Fix: Make the vest run with Kinect by default (even not set from the web server side)
    [main.py]
2015-08-17 Fix initialization not performed in main function
    [main.py]
2015-09-07 Update README, add PDF schematics
    [driver unit.sch]
